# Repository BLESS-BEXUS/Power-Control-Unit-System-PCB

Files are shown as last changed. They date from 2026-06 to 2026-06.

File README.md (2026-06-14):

<p align="center">
    <br>
    <a href="https://bless-bexus.es">
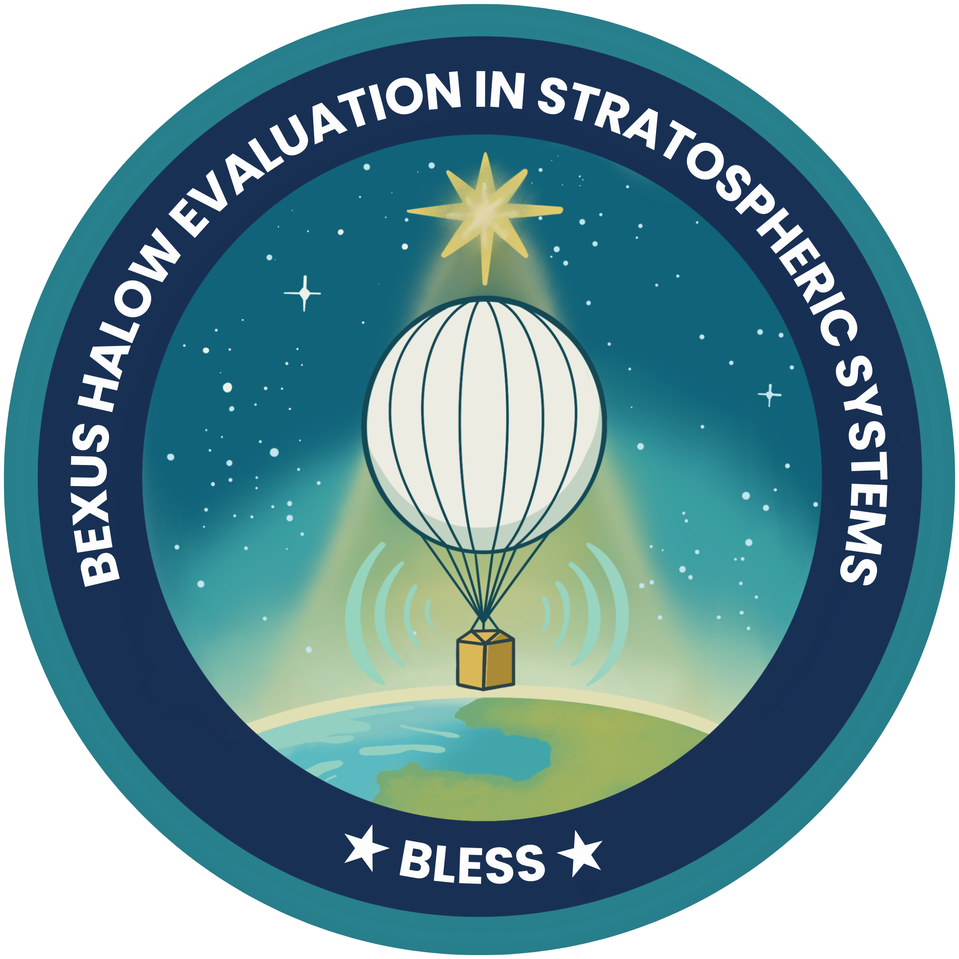
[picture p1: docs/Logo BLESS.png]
BLESS Logo
        
    </a>
</p>
<h1 align="center">Power Control Unit</h1>
<p align="center">
A custom PCB designed to distribute and regulate a single 28 V DC input into multiple power rails for embedded hardware systems.
</p>
<p align="center">
    
    
    <br>
    <a href="https://rexusbexus.net/">
        
    </a>
</p>

---

### Overview

The main goal of this PCB is to provide a compact and reliable power distribution stage for embedded systems that require several regulated voltage rails from a single DC input.

The board takes a nominal 28 V DC input and generates the regulated power rails required by the system:

- 3.3 V for logic, microcontrollers and digital sensors.
- 5 V for auxiliary electronics and interface modules.
- 12 V for higher-power loads such as heaters or dedicated subsystems.

This PCB centralizes power conversion, protection and distribution, making the overall system easier to integrate, debug and maintain.

### Purpose

This board is designed to simplify power management in systems where multiple voltage levels are required from a single supply line.

It is especially useful in applications that need:

- Centralized power distribution.
- Regulated low-voltage rails.
- Separation between logic, auxiliary and high-power loads.
- Protection against electrical faults.
- Cleaner wiring between subsystems.
- Easier integration with the rest of the electronics.

### Main Features

- Single 28 V DC input.
- Regulated 3.3 V output rail.
- Regulated 5 V output rail.
- Regulated 12 V output rail.
- TRACO POWER DC/DC converters.
- Input protection stage.
- Reverse-polarity protection.
- Fuse protection.
- Decoupling and filtering capacitors.
- Dedicated outputs for different subsystem power rails.
- Custom KiCad symbols, footprints and 3D models.

---

<h3 align="center">Contributing</h3>
<p align="center">
·
    <a href="./CODE_OF_CONDUCT.md">Code of Conduct</a>
    ·
    <a href="./CONTRIBUTING.md">Contributing Guide</a>
    ·
</p>
<p align="center">We welcome collaboration from the aerospace and hardware community. For major changes or data inquiries, please open an issue first.</p>
<h3 align="center">License</h3>
<pre align="center">Copyright © 2025-2026 The BLESS Project Team<br><br>This Source Code Form is subject to the terms of the Mozilla Public<br>License, v. 2.0. If a copy of the MPL was not distributed with this<br>file, You can obtain one at http://mozilla.org/MPL/2.0/.</pre>
<h3 align="center">Credits & Team</h3>
<p align="center">Supported by the REXUS/BEXUS Program and our generous sponsors.</p>
<p align="center">
    <a href="https://github.com/BLESS-BEXUS/Power-Control-Unit-System-PCB/graphs/contributors">
        
    </a>
</p>

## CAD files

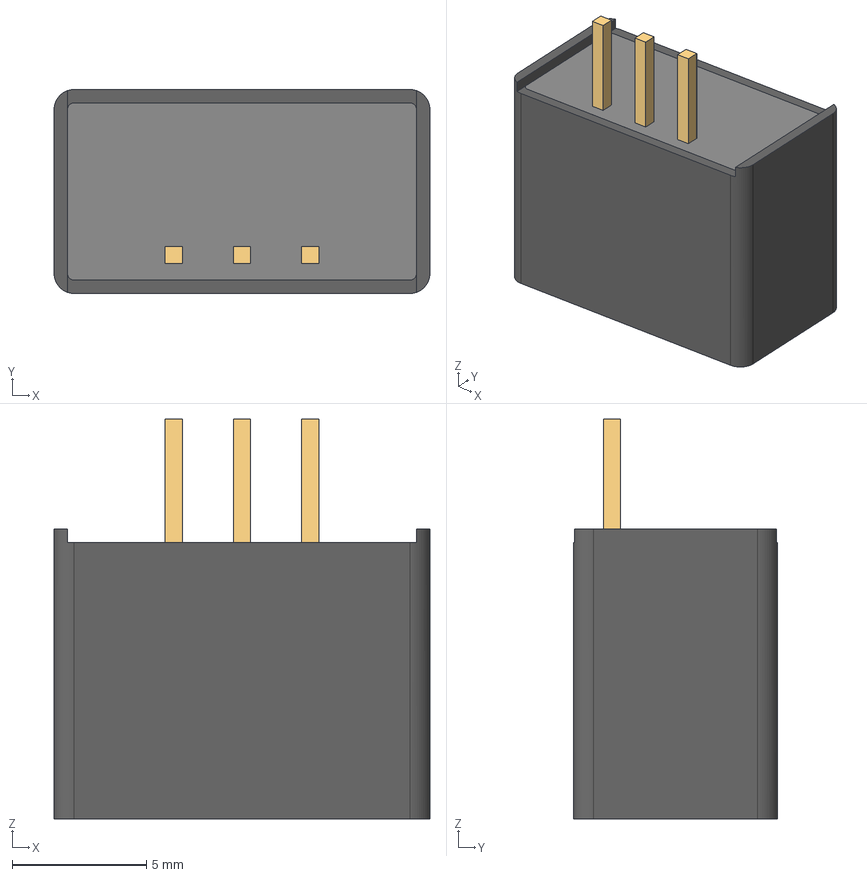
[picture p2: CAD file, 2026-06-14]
steps/TSR_3-24120N.stp
14.0 x 7.60 x 14.9 mm
CASE-00
膠-00
PIN-00 x 3

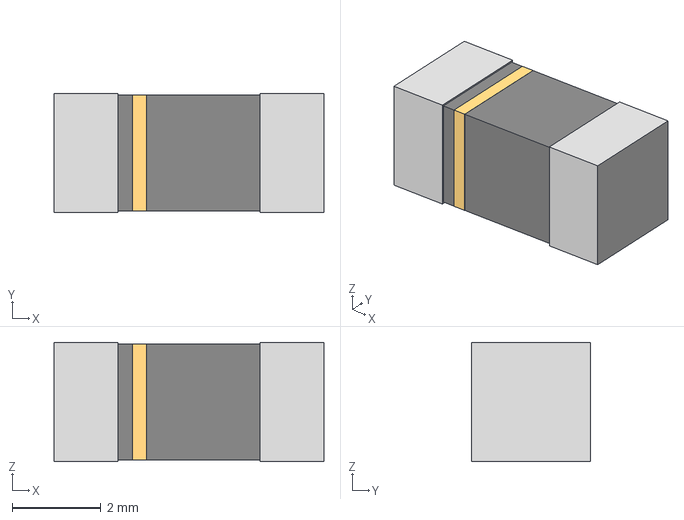
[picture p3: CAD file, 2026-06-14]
steps/0451Series_LTF.step
6.10 x 2.69 x 2.69 mm

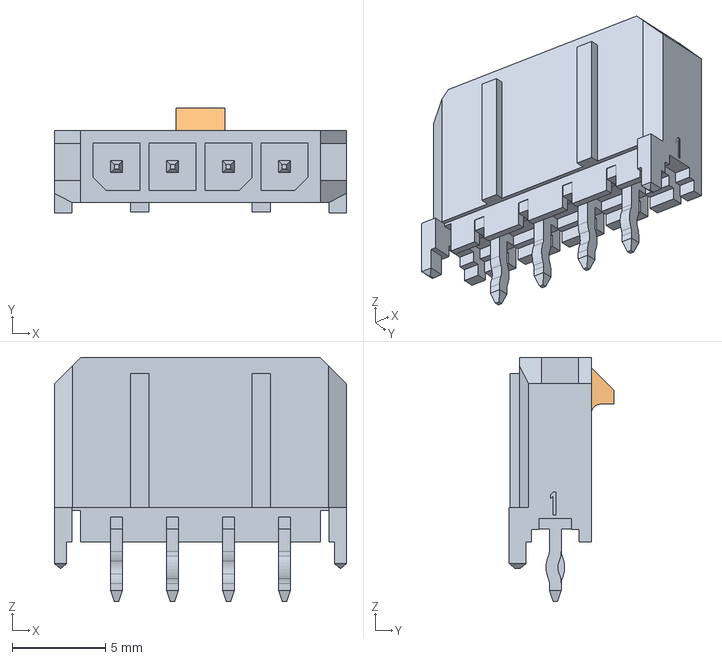
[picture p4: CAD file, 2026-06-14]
steps/43650-0415.stp
15.7 x 5.61 x 13.1 mm

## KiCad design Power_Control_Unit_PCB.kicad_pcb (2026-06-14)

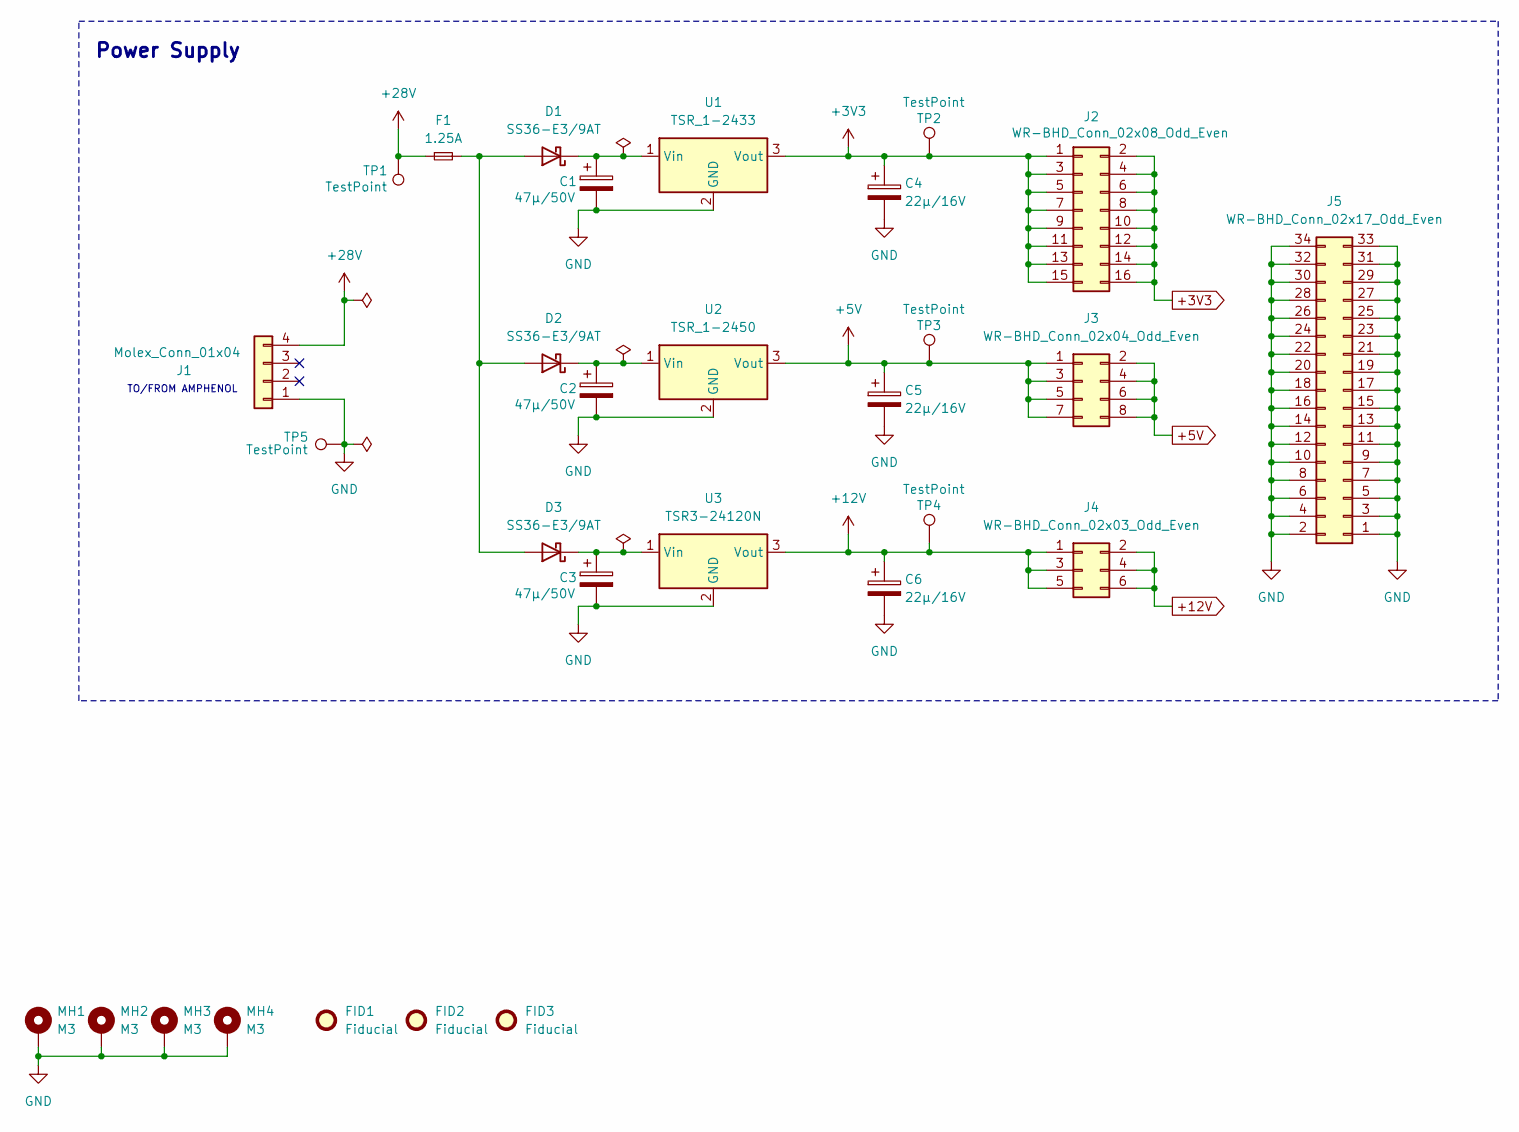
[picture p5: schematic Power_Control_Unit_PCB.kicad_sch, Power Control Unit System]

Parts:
C1, C2, C3: 47µ/50V; CP_Elec_6.3x7.7; Manufacturer Part Number EEE-FT1H470AP; LCSC C92059
C4, C5, C6: 22µ/16V; CP_Elec_5x5.8; Manufacturer Part Number EEE-FK1C220R; LCSC C242120
D1, D2, D3: SS36-E3/9AT; D_SMC; Manufacturer Part Number SS36-E3/9AT; LCSC C3009064
F1: 1.25A; Fuse_Littelfuse-NANO2-451_453; Manufacturer Part Number 04511.25MRL; LCSC 2410
FID1, FID2, FID3: Fiducial; Fiducial_1mm_Mask2mm
J1: Molex_Conn_01x04; Molex_Micro-Fit_3.0_43650-0415_1x04_P3.00mm_Vertical; Manufacturer Part Number 43650-0415; LCSC C293547
J2: WR-BHD_Conn_02x08_Odd_Even; IDC-Header_2x08_P2.54mm_Vertical; Manufacturer Part Number 61201621621; LCSC C3406
J3: WR-BHD_Conn_02x04_Odd_Even; IDC-Header_2x04_P2.54mm_Vertical; Manufacturer Part Number 61200821621; LCSC C9135
J4: WR-BHD_Conn_02x03_Odd_Even; IDC-Header_2x03_P2.54mm_Vertical; Manufacturer Part Number 61200621621; LCSC C11214
J5: WR-BHD_Conn_02x17_Odd_Even; IDC-Header_2x17_P2.54mm_Vertical; Manufacturer Part Number 61203421621; LCSC C20920
MH1, MH2, MH3, MH4: M3; MountingHole_3.2mm_M3_Pad_Via
TP1, TP2, TP3, TP4, TP5: TestPoint; TestPoint_Pad_D1.0mm
U1: TSR_1-2433; Converter_DCDC_TRACO_TSR-1_THT; Manufacturer Part Number TSR 1-2433; LCSC C5455553
U2: TSR_1-2450; Converter_DCDC_TRACO_TSR-1_THT; Manufacturer Part Number TSR 1-2450; LCSC C6886877
U3: TSR3-24120N; Converter_DCDC_TRACO_TSR2-24xxN_TSR2-24xxxN_THT; Manufacturer Part Number TSR 3-24120N; LCSC C45533985

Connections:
+3V3: C4.1, J2.1, J2.2, J2.3, J2.4, J2.5, J2.6, J2.7, J2.8, J2.9, J2.10, J2.11, J2.12, J2.13, J2.14, J2.15, J2.16, TP2.1 (1_1), U1.3 (Vout)
+5V: C5.1, J3.1, J3.2, J3.3, J3.4, J3.5, J3.6, J3.7, J3.8, TP3.1 (1_1), U2.3 (Vout)
+12V: C6.1, J4.1, J4.2, J4.3, J4.4, J4.5, J4.6, TP4.1 (1_1), U3.3 (Vout)
+28V: F1.1, J1.4, TP1.1 (1_1)
GND: C1.2, C2.2, C3.2, C4.2, C5.2, C6.2, J1.1, J5.1, J5.2, J5.3, J5.4, J5.5, J5.6, J5.7, J5.8, J5.9, J5.10, J5.11, J5.12, J5.13, J5.14, J5.15, J5.16, J5.17, J5.18, J5.19, J5.20, J5.21, J5.22, J5.23, J5.24, J5.25, J5.26, J5.27, J5.28, J5.29, J5.30, J5.31, J5.32, J5.33, J5.34, MH1.1 (1_1), MH2.1 (1_1), MH3.1 (1_1), MH4.1 (1_1), TP5.1 (1_1), U1.2 (GND), U2.2 (GND), U3.2 (GND)
unnamed: D1.2 (A), D2.2 (A), D3.2 (A), F1.2
unnamed: C1.1, D1.1 (K), U1.1 (Vin)
unnamed: C2.1, D2.1 (K), U2.1 (Vin)
unnamed: C3.1, D3.1 (K), U3.1 (Vin)

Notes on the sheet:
TO/FROM AMPHENOL
Power Supply

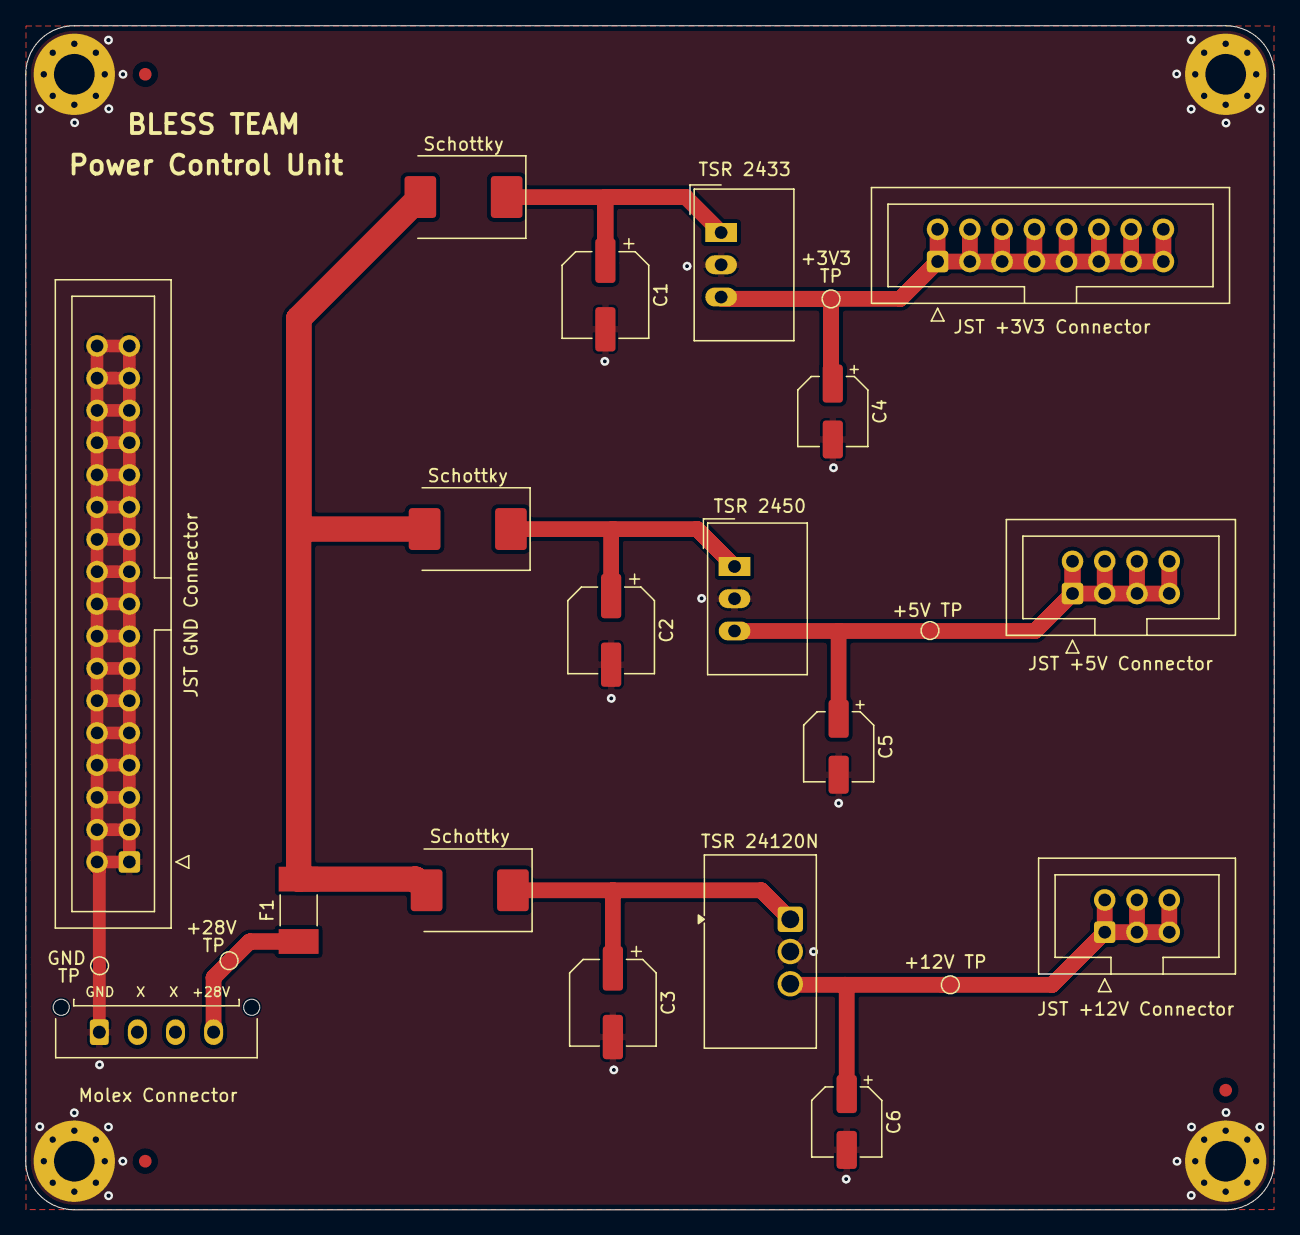
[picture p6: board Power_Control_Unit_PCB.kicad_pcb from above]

Board: 2 copper layers, 98.3 x 93.2 mm, 30 parts (0 on the bottom side), 9 nets.

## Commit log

2026-06-14 Add project KiCad initial files
    [Power_Control_Unit_PCB.kicad_pcb, Power_Control_Unit_PCB.kicad_sch]
2026-06-14 PCU Schematics
    [Power_Control_Unit_PCB.kicad_sch]
2026-06-14 PCU Initial PCB design and routing
    [0451Series_LTF.step, 43650-0415.stp, Power_Control_Unit_PCB.kicad_pcb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]
2026-06-14 PCU pcb design and added copper zones por power planes
    [Power_Control_Unit_PCB.kicad_pcb, Power_Control_Unit_PCB.kicad_sch]
